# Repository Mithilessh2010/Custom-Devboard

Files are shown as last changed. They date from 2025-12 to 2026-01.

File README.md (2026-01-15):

# Custom DevBoard

## Board Render


## PCB Layout


## Schematic


## Bill of Materials (BOM)

| Reference | Part Name | Description |
| --- | --- | --- |
| U1 | RP2040 | Main microcontroller |
| U2 | MCP1700 | 3.3V voltage regulator |
| U3 | W25Q16 | External flash memory |
| Y1 | 12 MHz Crystal | Clock source for RP2040 |
| J1 | USB Connector  | Power and programming |
| R* | Resistors | Pull-ups, pull-downs, and general use |
| C* | Capacitors | Power filtering and stability |
| SW* | Buttons | Boot and reset buttons |
| PCB | JLCPCB | $ 101.3 |




## Custom Features
It works like a normal devboard but has bit, of changes such as lights to indicate various things, and buttons to reset, etc.

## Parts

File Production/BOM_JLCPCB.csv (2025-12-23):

JLCPCB BOM Tool - BOM Matching
BOM name：BOM-JLCPCB Assembly Order.xlsx |  |  | Download Time：2025-10-01 10:21:17 |  |  |  | * Our matching results are updated in real-time, but stock and prices may change. If it's been over 24 hours, please re-match before placing your order.
PCB Assembled Qty：5 |  |  | Est. Total Price：11.5620
Your BOM |  |  |  |  | Matched Parts |  |  |  |  |  |  | Order Information
Top Designator | Bottom Designator | Comment | Footprint | JLCPCB Part # | Matches | Part # | Manufacturer | Footprint | Description | Category | Warning | JLCPCB Part # | Product link | Lib Type | Qty | Source | Total Price ($)
C1,C10 |  | 1uF | C_0402_1005Metric |  | Select by Customer | CL05A105KA5NQNC | Samsung Electro-Mechanics | 0402 | 1uF 25V X5R ±10% 0402 Multilayer Ceramic Capacitors MLCC - SMD/SMT ROHS | Multilayer Ceramic Capacitors MLCC - SMD/SMT |  | C52923 | https://jlcpcb.com/partdetail/53938-CL05A105KA5NQNC/C52923 | Basic | 10 | 10 JLCPCB | 0.029
C8,C6,C5,C4,C2,C7,C11,C9,C12,C17,C3 |  | 0.1uF | C_0402_1005Metric |  | Select by Customer | CL05B104KO5NNNC | Samsung Electro-Mechanics | 0402 | 100nF 16V X7R ±10% 0402 Multilayer Ceramic Capacitors MLCC - SMD/SMT ROHS | Multilayer Ceramic Capacitors MLCC - SMD/SMT | 1.The comment (CL05B104KO5NNNC) of this part does not match the one (0.1uF) provided in your BOM. Please confirm; | C1525 | https://jlcpcb.com/partdetail/1877-CL05B104KO5NNNC/C1525 | Basic | 55 | 55 JLCPCB | 0.0605
C13,C14 |  | 10uF | C_0603_1608Metric |  | Select by System | CL10A106KP8NNNC | Samsung Electro-Mechanics | 0603 | 10V 10uF X5R ±10% 0603 Multilayer Ceramic Capacitors MLCC - SMD/SMT ROHS | Multilayer Ceramic Capacitors MLCC - SMD/SMT |  | C19702 | https://jlcpcb.com/partdetail/20411-CL10A106KP8NNNC/C19702 | Basic | 10 | 10 JLCPCB | 0.056
C16,C15 |  | 33pF | C_0402_1005Metric |  | Select by Customer | 0402CG330J500NT | FH (Guangdong Fenghua Advanced Tech) | 0402 | 33pF 50V C0G ±5% 0402 Multilayer Ceramic Capacitors MLCC - SMD/SMT ROHS | Multilayer Ceramic Capacitors MLCC - SMD/SMT |  | C1562 | https://jlcpcb.com/partdetail/1914-0402CG330J500NT/C1562 | Basic | 10 | 10 JLCPCB | 0.01
J1 |  | USB_C_Receptacle_USB2.0_14P | USB_C_Receptacle_HRO_TYPE-C-31-M-12 |  | Select by Customer | TYPE-C-31-M-12 | Korean Hroparts Elec | SMD | 1 16P 5A Female Type-C SMD USB Connectors ROHS | USB Connectors |  | C165948 | https://jlcpcb.com/partdetail/Korean_HropartsElec-TYPE_C_31_M12/C165948 | Extended | 5 | 5 JLCPCB | 0.8445
J3,J2 |  | Conn_01x20 | PinHeader_1x20_P2.54mm_Vertical |  | Select by Customer | 2.54-1*20P直针 | BOOMELE(Boom Precision Elec) | 插件,P=2.54mm | -40℃~+105℃ 1 1x20P 2.54mm 20P 3A Black Brass Pin Header Through Hole Plugin,P=2.54mm Pin Headers ROHS | Pin Headers |  | C50981 | https://jlcpcb.com/partdetail/51993-2_54_1_20P/C50981 | Extended | 0 | 0 JLCPCB | 0
J4 |  | Conn_01x03 | PinHeader_1x03_P2.54mm_Vertical |  | Select by Customer | 1.27-1*3P针 | BOOMELE(Boom Precision Elec) | 插件,P=1.27mm | -55℃~+105℃ 1 1.27mm 1mm 1x3P 2.3mm 3A 3P 3mm Black Brass Pin Header Through Hole Plugin,P=1.27mm Pin Headers ROHS | Pin Headers |  | C24980 | https://jlcpcb.com/partdetail/25717-1_27_1_3P/C24980 | Extended | 0 | 0 JLCPCB | 0
R2,R1 |  | 5.1K | R_0402_1005Metric |  | Select by Customer | 0402WGF5101TCE | UNI-ROYAL(Uniroyal Elec) | 0402 | -55℃~+155℃ 5.1kΩ 50V 62.5mW Thick Film Resistor ±1% ±100ppm/℃ 0402 Chip Resistor - Surface Mount ROHS | Chip Resistor - Surface Mount |  | C25905 | https://jlcpcb.com/partdetail/26648-0402WGF5101TCE/C25905 | Basic | 10 | 10 JLCPCB | 0.005
R3,R4 |  | 27 | R_0402_1005Metric |  | Select by Customer | 0402WGF270JTCE | UNI-ROYAL(Uniroyal Elec) | 0402 | -55℃~+155℃ 27Ω 50V 62.5mW Thick Film Resistor ±1% ±100ppm/℃ 0402 Chip Resistor - Surface Mount ROHS | Chip Resistor - Surface Mount | 1.The comment (0402WGF270JTCE) of this part does not match the one (27) provided in your BOM. Please confirm; | C25100 | https://jlcpcb.com/partdetail/25843-0402WGF270JTCE/C25100 | Extended | 22 | 22 JLCPCB | 0.011
R6,R5 |  | 1K | R_0402_1005Metric |  | Select by Customer | 0402WGF1001TCE | UNI-ROYAL(Uniroyal Elec) | 0402 | -55℃~+155℃ 1kΩ 50V 62.5mW Thick Film Resistor ±1% ±100ppm/℃ 0402 Chip Resistor - Surface Mount ROHS | Chip Resistor - Surface Mount | 1.The comment (0402WGF1001TCE) of this part does not match the one (1K) provided in your BOM. Please confirm; | C11702 | https://jlcpcb.com/partdetail/12256-0402WGF1001TCE/C11702 | Basic | 10 | 10 JLCPCB | 0.005
R7 |  | 10K | R_0402_1005Metric |  | Select by Customer | 0402WGF1002TCE | UNI-ROYAL(Uniroyal Elec) | 0402 | -55℃~+155℃ 10kΩ 50V 62.5mW Thick Film Resistor ±1% ±100ppm/℃ 0402 Chip Resistor - Surface Mount ROHS | Chip Resistor - Surface Mount | 1.The comment (0402WGF1002TCE) of this part does not match the one (10K) provided in your BOM. Please confirm; | C25744 | https://jlcpcb.com/partdetail/26487-0402WGF1002TCE/C25744 | Basic | 5 | 5 JLCPCB | 0.0025
SW1 |  | SW_Push | SW_Push_SPST_NO_Alps_SKRK |  | Select by Customer | TS-1088-AR02016 | XUNPU | SMD,4x3mm | -30℃~+80℃ 1.6N 100,000 Cycles 12V 2mm 3mm 4mm 50mA Black Round Button SMD(SMT) Tab SPST Surface Mount,Vertical Without Bracket SMD,4x3mm Tactile Switches ROHS | Tactile Switches |  | C720477 | https://jlcpcb.com/partdetail/XUNPU-TS_1088AR02016/C720477 | Basic | 5 | 5 JLCPCB | 0.2115
U1 |  | RP2040 | QFN-56-1EP_7x7mm_P0.4mm_EP3.2x3.2mm |  | Select by Customer | RP2040 | Raspberry Pi | LQFN-56(7x7) | 12bit 133MHz 30 LQFN-56(7x7) Microcontrollers (MCU/MPU/SOC) ROHS | Microcontrollers (MCU/MPU/SOC) |  | C2040 | https://jlcpcb.com/partdetail/RaspberryPi-RP2040/C2040 | Extended | 5 | 5 JLCPCB | 5.5275
U2 |  | MCP1700x-330xxTT | SOT-23 |  | Select by Customer | MCP1700T-3302E/TT | Microchip Tech | SOT-23 | -40℃~+125℃@(Tj) 1 1.6uA 178mV@(250mA) 250mA 3.3V 44dB@(100Hz) 6V Fixed Over Temperature Protection Positive SOT-23 Voltage Regulators - Linear, Low Drop Out (LDO) Regulators ROHS | Voltage Regulators - Linear, Low Drop Out (LDO) Regulators |  | C39051 | https://jlcpcb.com/partdetail/MicrochipTech-MCP1700T_3302ETT/C39051 | Extended | 5 | 5 JLCPCB | 1.717
U4 |  | W25Q16JVUXIQTR | Winbond_USON-8-1EP_3x2mm_P0.5mm_EP0.2x1.6mm |  | Select by Customer | W25Q16JVUXIQ | Winbond Elec | USON-8-EP(2x3) | 100,000 Cycles 133MHz 16Mbit 2.7V~3.6V 20 Years 3ms SPI USON-8-EP(2x3) NOR FLASH ROHS | NOR FLASH | 1.The comment (W25Q16JVUXIQ) of this part does not match the one (W25Q16JVUXIQTR) provided in your BOM. Please confirm; | C2843335 | https://jlcpcb.com/partdetail/WinbondElec-W25Q16JVUXIQ/C2843335 | Extended | 5 | 5 JLCPCB | 2.76
Y1 |  | 12MHz | Crystal_SMD_3225-4Pin_3.2x2.5mm |  | Select by Customer | X322512MSB4SI | YXC Crystal Oscillators | SMD3225-4P | -40℃~+85℃ 12MHz 20pF Crystal Oscillator ±10ppm ±20ppm SMD3225-4P Crystals ROHS | Crystals |  | C9002 | https://jlcpcb.com/partdetail/YXC_CrystalOscillators-X322512MSB4SI/C9002 | Basic | 5 | 5 JLCPCB | 0.3225

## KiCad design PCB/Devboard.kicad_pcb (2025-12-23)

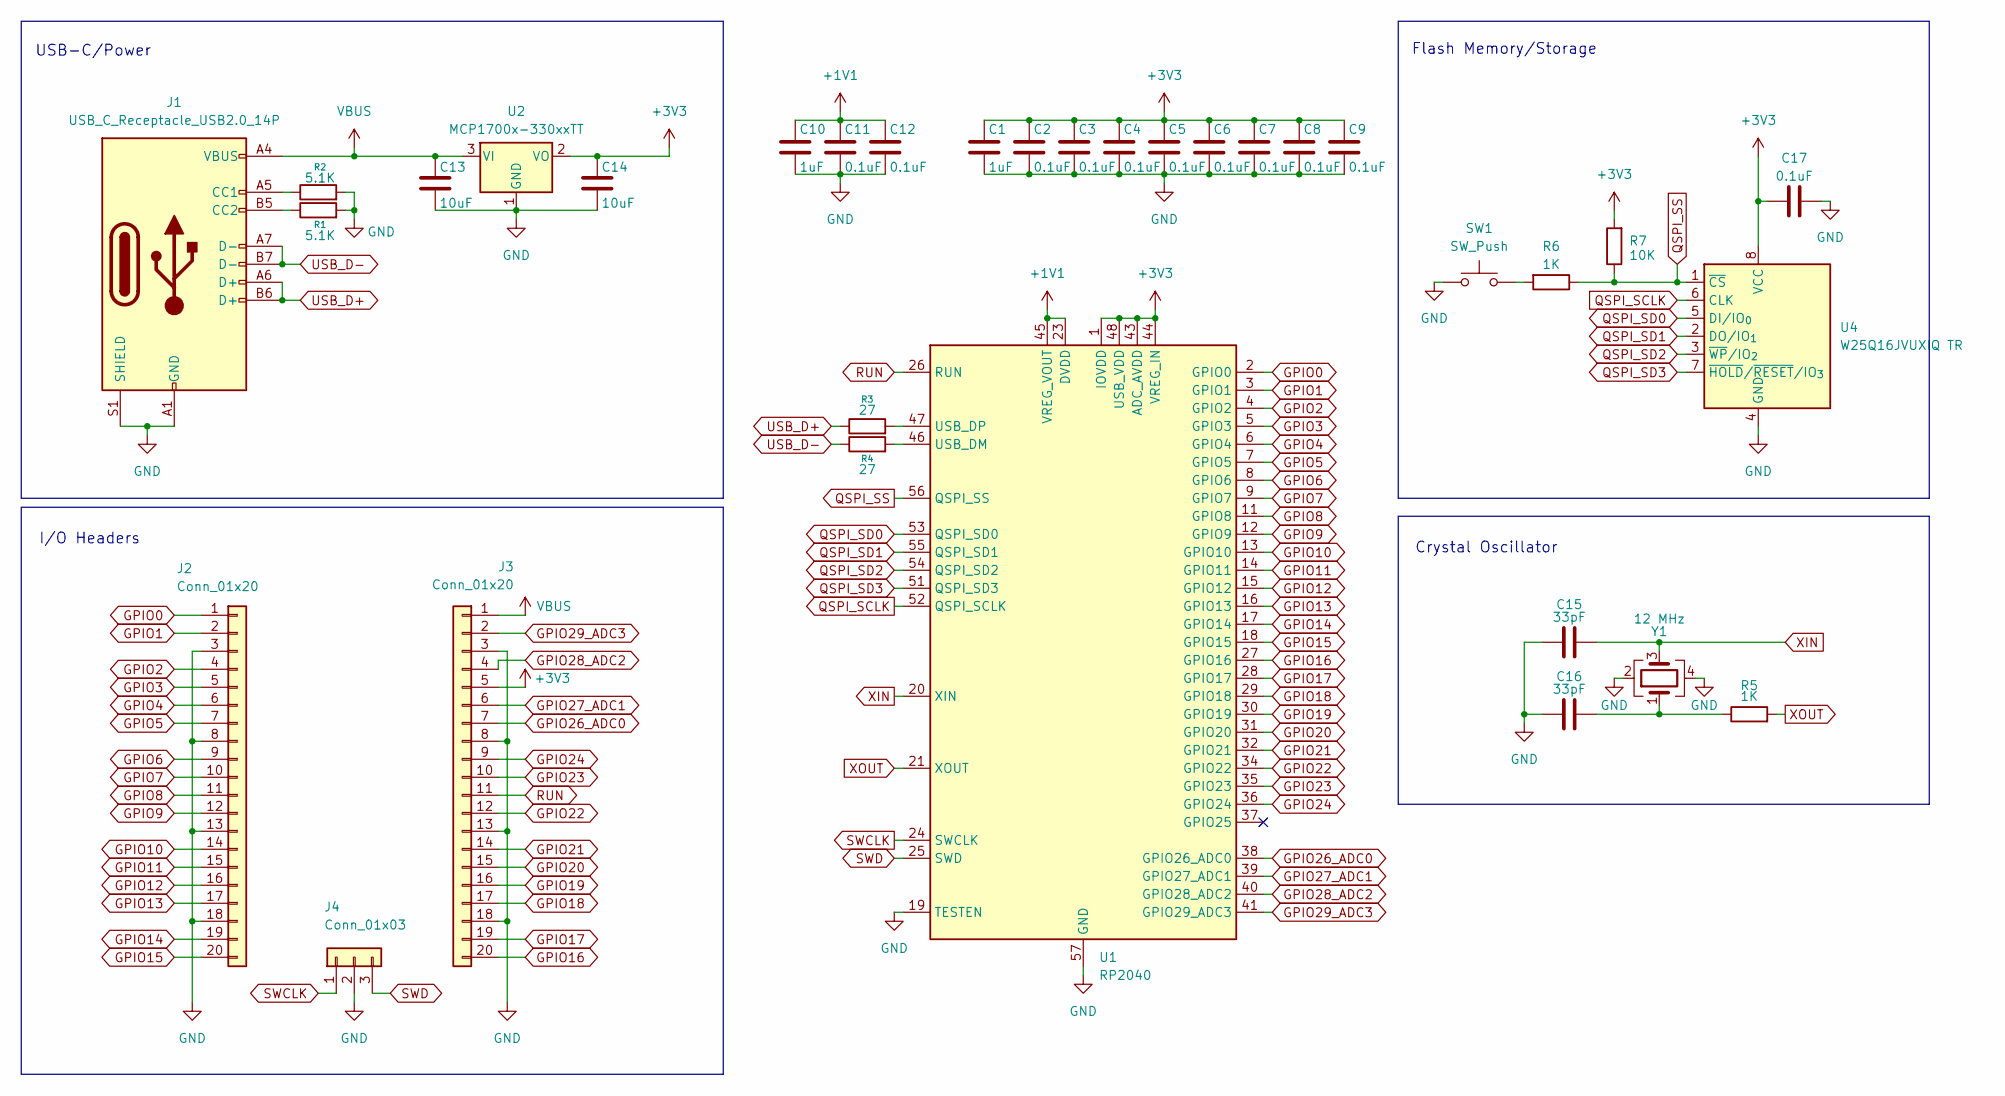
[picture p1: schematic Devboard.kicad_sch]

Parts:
C1, C10: 1uF; C_0402_1005Metric
C2, C3, C4, C5, C6, C7, C8, C9, C11, C12, C17: 0.1uF; C_0402_1005Metric
C13, C14: 10uF; C_0603_1608Metric
C15, C16: 33pF; C_0402_1005Metric
J1: USB_C_Receptacle_USB2.0_14P; USB_C_Receptacle_HRO_TYPE-C-31-M-12
J2, J3: Conn_01x20; PinHeader_1x20_P2.54mm_Vertical
J4: Conn_01x03; PinHeader_1x03_P2.54mm_Vertical
R1, R2: 5.1K; R_0402_1005Metric
R3, R4: 27; R_0402_1005Metric
R5, R6: 1K; R_0402_1005Metric
R7: 10K; R_0402_1005Metric
SW1: SW_Push; SW_Push_SPST_NO_Alps_SKRK
U1: RP2040; QFN-56-1EP_7x7mm_P0.4mm_EP3.2x3.2mm
U2: MCP1700x-330xxTT; SOT-23
U4: W25Q16JVUXIQ TR; Winbond_USON-8-1EP_3x2mm_P0.5mm_EP0.2x1.6mm
Y1: 12 MHz; Crystal_SMD_3225-4Pin_3.2x2.5mm

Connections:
+1V1: C10.1, C11.1, C12.1, U1.23 (DVDD), U1.45 (VREG_VOUT), U1.50 (DVDD)
+3V3: C1.1, C2.1, C3.1, C4.1, C5.1, C6.1, C7.1, C8.1, C9.1, C14.1, C17.1, J3.5, R7.2, U1.1 (IOVDD), U1.10 (IOVDD), U1.22 (IOVDD), U1.33 (IOVDD), U1.42 (IOVDD), U1.43 (ADC_AVDD), U1.44 (VREG_IN), U1.48 (USB_VDD), U1.49 (IOVDD), U2.2 (VO), U4.8 (VCC)
GND: C1.2, C2.2, C3.2, C4.2, C5.2, C6.2, C7.2, C8.2, C9.2, C10.2, C11.2, C12.2, C13.2, C14.2, C15.1, C16.1, C17.2, J1.A1 (GND), J1.A12 (GND), J1.B1 (GND), J1.B12 (GND), J1.S1 (SHIELD), J2.3, J2.8, J2.13, J2.18, J3.3, J3.8, J3.13, J3.18, J4.2, R1.2, R2.2, SW1.1, U1.19 (TESTEN), U1.57 (GND), U2.1 (GND), U4.4 (GND), Y1.2, Y1.4
GPIO0: J2.1, U1.2 (GPIO0)
GPIO1: J2.2, U1.3 (GPIO1)
GPIO2: J2.4, U1.4 (GPIO2)
GPIO3: J2.5, U1.5 (GPIO3)
GPIO4: J2.6, U1.6 (GPIO4)
GPIO5: J2.7, U1.7 (GPIO5)
GPIO6: J2.9, U1.8 (GPIO6)
GPIO7: J2.10, U1.9 (GPIO7)
GPIO8: J2.11, U1.11 (GPIO8)
GPIO9: J2.12, U1.12 (GPIO9)
GPIO10: J2.14, U1.13 (GPIO10)
GPIO11: J2.15, U1.14 (GPIO11)
GPIO12: J2.16, U1.15 (GPIO12)
GPIO13: J2.17, U1.16 (GPIO13)
GPIO14: J2.19, U1.17 (GPIO14)
GPIO15: J2.20, U1.18 (GPIO15)
GPIO16: J3.20, U1.27 (GPIO16)
GPIO17: J3.19, U1.28 (GPIO17)
GPIO18: J3.17, U1.29 (GPIO18)
GPIO19: J3.16, U1.30 (GPIO19)
GPIO20: J3.15, U1.31 (GPIO20)
GPIO21: J3.14, U1.32 (GPIO21)
GPIO22: J3.12, U1.34 (GPIO22)
GPIO23: J3.10, U1.35 (GPIO23)
GPIO24: J3.9, U1.36 (GPIO24)
GPIO26_ADC0: J3.7, U1.38 (GPIO26_ADC0)
GPIO27_ADC1: J3.6, U1.39 (GPIO27_ADC1)
GPIO28_ADC2: J3.4, U1.40 (GPIO28_ADC2)
GPIO29_ADC3: J3.2, U1.41 (GPIO29_ADC3)
unnamed: C16.2, R5.1, Y1.1
unnamed: J1.A5 (CC1), R2.1
unnamed: J1.B5 (CC2), R1.1
unnamed: R6.2, SW1.2
unnamed: R4.2, U1.46 (USB_DM)
unnamed: R3.2, U1.47 (USB_DP)
QSPI_SCLK: U1.52 (QSPI_SCLK), U4.6 (CLK)
QSPI_SD0: U1.53 (QSPI_SD0), U4.5 (DI/IO_{0})
QSPI_SD1: U1.55 (QSPI_SD1), U4.2 (DO/IO_{1})
QSPI_SD2: U1.54 (QSPI_SD2), U4.3 (~WP/IO_{2})
QSPI_SD3: U1.51 (QSPI_SD3), U4.7 (~HOLD/~RESET/IO_{3})
QSPI_SS: R6.1, R7.1, U1.56 (QSPI_SS), U4.1 (~CS)
RUN: J3.11, U1.26 (RUN)
SWCLK: J4.1, U1.24 (SWCLK)
SWD: J4.3, U1.25 (SWD)
USB_D+: J1.A6 (D+), J1.B6 (D+), R3.1
USB_D-: J1.A7 (D-), J1.B7 (D-), R4.1
VBUS: C13.1, J1.A4 (VBUS), J1.A9 (VBUS), J1.B4 (VBUS), J1.B9 (VBUS), J3.1, U2.3 (VI)
XIN: C15.2, U1.20 (XIN), Y1.3
XOUT: R5.2, U1.21 (XOUT)

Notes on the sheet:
Flash Memory/Storage
I/O Headers
Crystal Oscillator
USB-C/Power

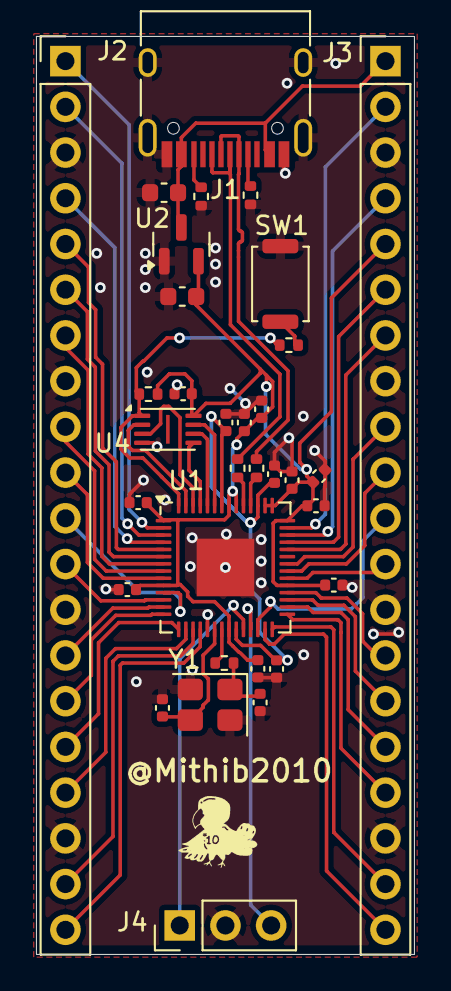
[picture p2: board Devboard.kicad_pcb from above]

Board: 2 copper layers, 21.0 x 51.0 mm, 33 parts (0 on the bottom side), 52 nets.

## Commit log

2026-01-15 Update README with images and power details
    Added images and updated power specifications.
2026-01-15 Update README with custom features and remove power info
    Removed power section and updated custom features description.
